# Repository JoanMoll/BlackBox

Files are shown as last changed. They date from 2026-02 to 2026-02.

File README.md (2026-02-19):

# BlackBox — Room Health / Environmental Monitoring PCB

Custom KiCad PCB for a battery-powered, ESP32-class device intended to monitor room/environment conditions and log data locally.

## Design previews

### 3D view
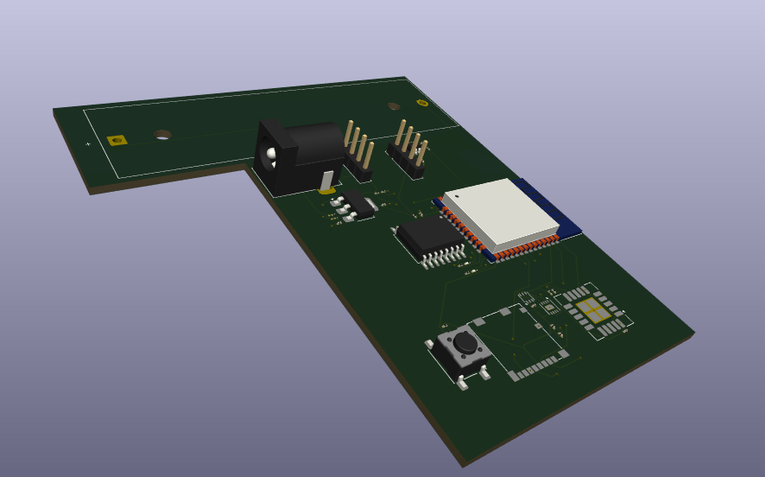
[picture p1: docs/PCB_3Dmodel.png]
PCB 3D Render


### PCB layout
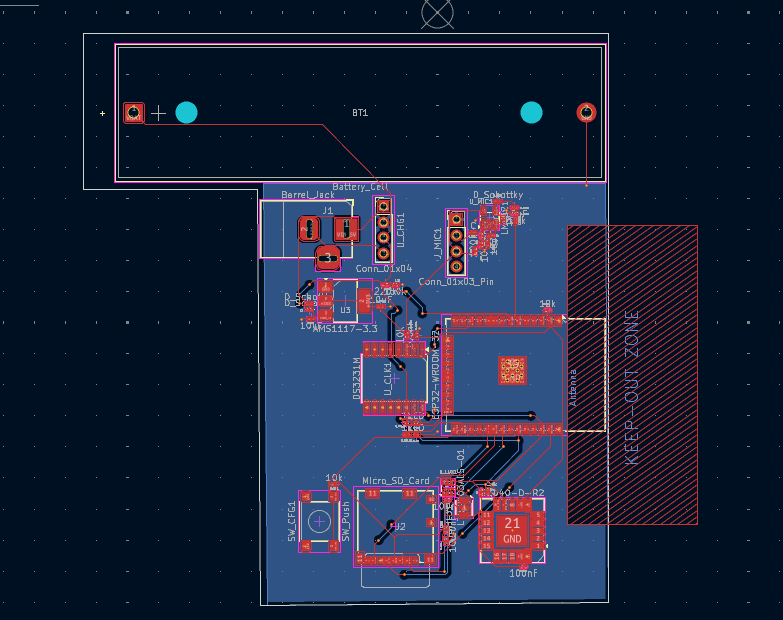
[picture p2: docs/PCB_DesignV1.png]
PCB Layout


### Schematic
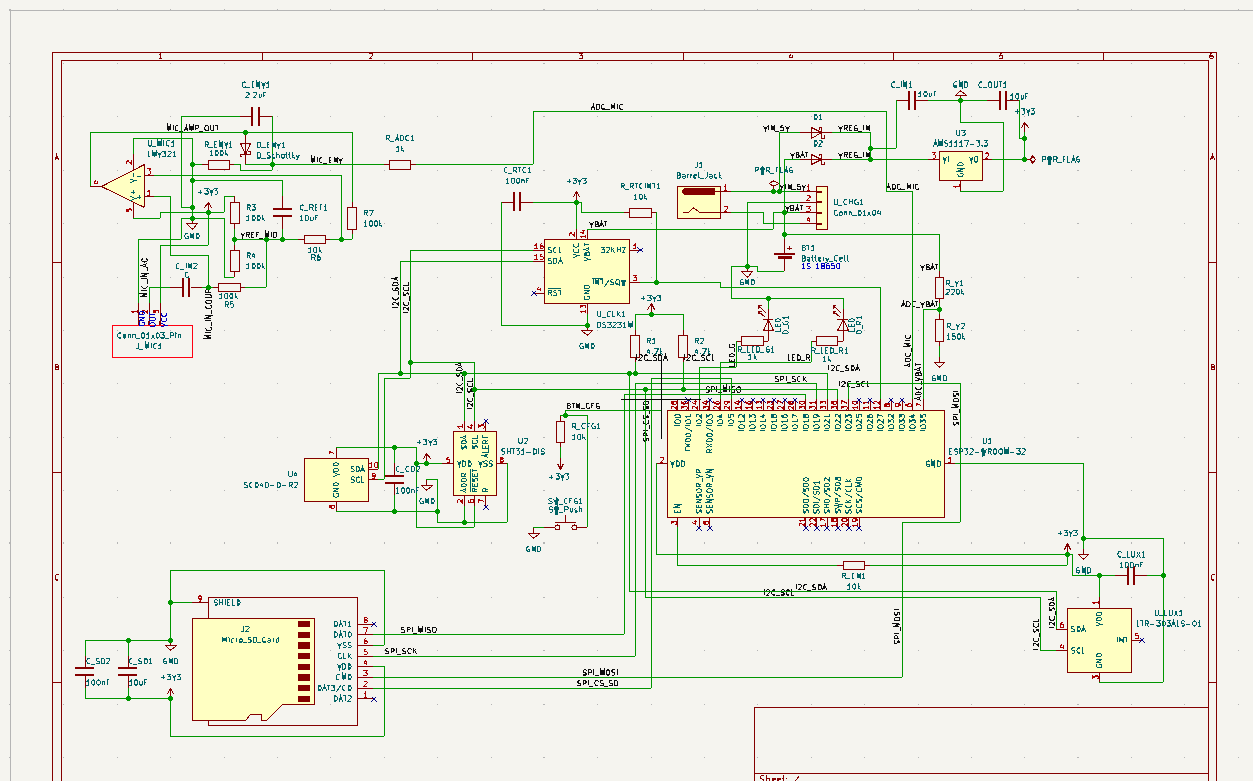
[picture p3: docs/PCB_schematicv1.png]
Schematic


## Project overview
BlackBox is a hardware design project focused on a practical embedded system that combines sensing, local storage, battery operation, and an ESP32-class MCU. The goal is a compact “room health” monitoring unit that can collect measurements and store them for later analysis.

## Intended system (high-level)
- MCU / Wireless: ESP32-class microcontroller (e.g., ESP32-S3)
- Sensors: LDR (ambient light), ultrasonic (distance/proximity), plus analog sensor input(s)
- Analog front-end: LMV321 op-amp stage for signal conditioning/amplification
- Storage: micro-SD card for local data logging
- Power: battery input (VBAT) with 3.3 V regulation and battery management/protection

## Repository contents
- KiCad project: `.kicad_pro`
- Schematic: `.kicad_sch`
- PCB layout: `.kicad_pcb`
- 3D model export: `.step` (if included)
- Documentation images: `docs/pcb_3d.png`, `docs/pcb_layout.png`, `docs/schematic.png`

## How to open and review
1. Install KiCad (v7+ recommended).
2. Open the `.kicad_pro` file.
3. Review the schematic (`.kicad_sch`) and PCB layout (`.kicad_pcb`).
4. Run ERC (schematic checks) and DRC (PCB checks) inside KiCad.

## Status
- Schematic and PCB layout created
- Next: final DRC/ERC pass and documentation polish
- Next: order PCB and bring-up tests (power rails, SD, sensor IO)
- Next: firmware (sampling + logging format) and enclosure design

## Skills demonstrated
- End-to-end PCB design workflow in KiCad (schematic capture, layout, manufacturable design)
- Embedded hardware system design (power, sensing, analog conditioning, storage interfaces)
- Clear engineering documentation for review (renders + structured project summary)

## License
If no license file is included, all rights reserved (portfolio viewing only).

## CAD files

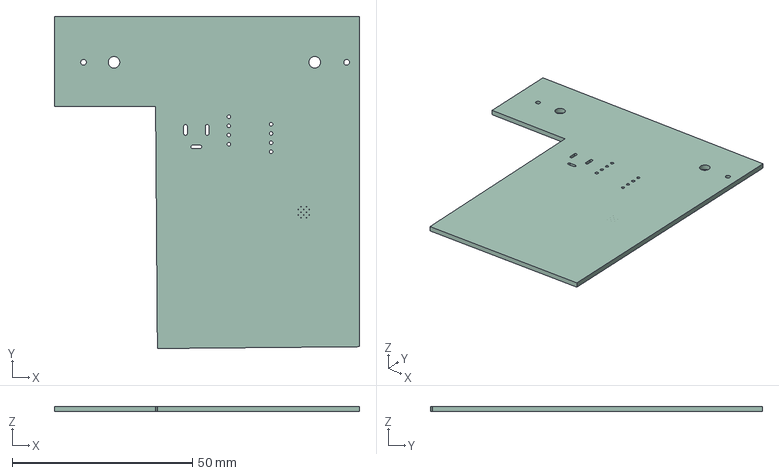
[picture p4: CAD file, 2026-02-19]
RoomHealthBlackBox.step
84.5 x 92.0 x 1.51 mm

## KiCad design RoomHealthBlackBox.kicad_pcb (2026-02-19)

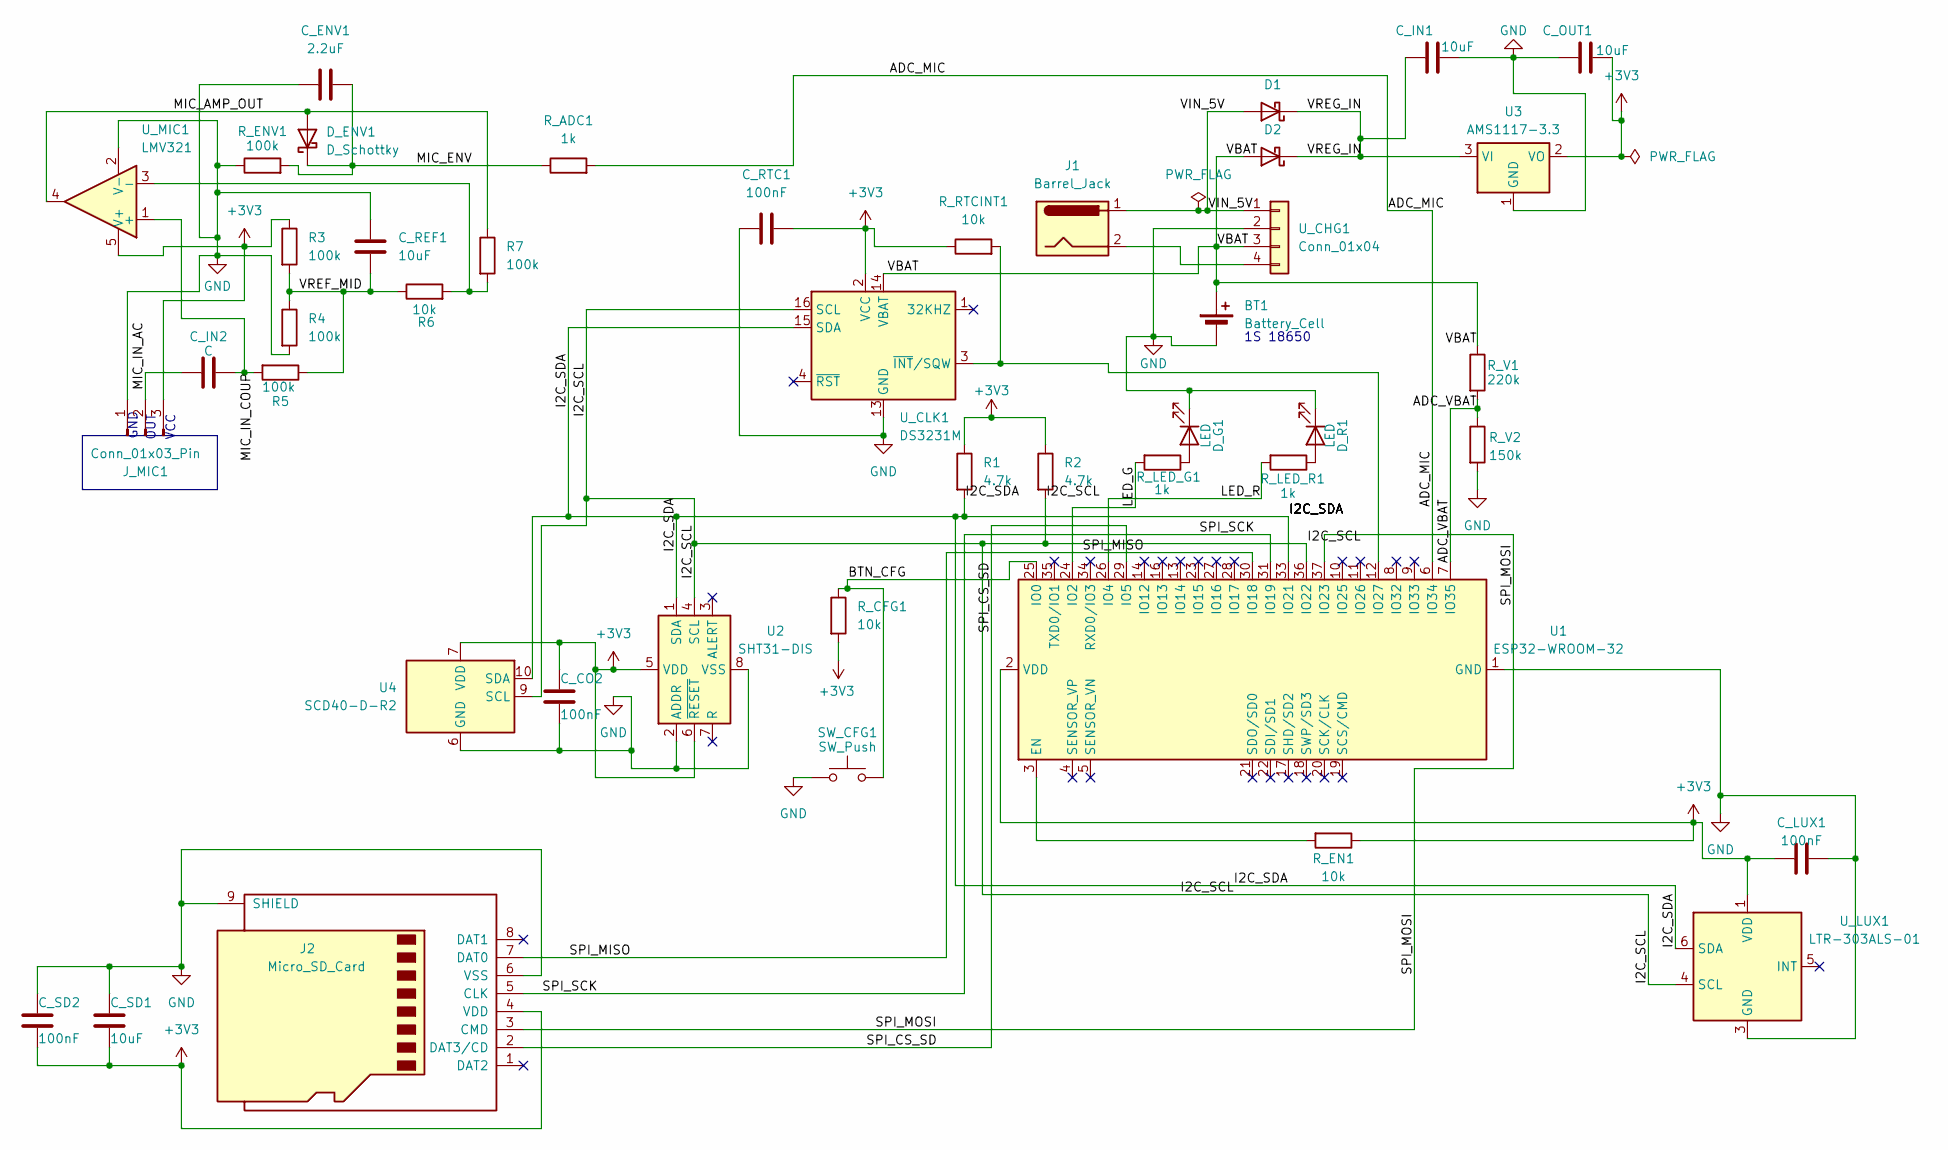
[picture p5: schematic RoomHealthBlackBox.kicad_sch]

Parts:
BT1: Battery_Cell; BatteryHolder_MPD_BH-18650-PC
C_CO2: 100nF; C_0201_0603Metric
C_ENV1: 2.2uF; C_0201_0603Metric
C_IN1: 10uF; C_0201_0603Metric
C_IN2: C; C_0201_0603Metric
C_LUX1: 100nF; C_0201_0603Metric
C_OUT1: 10uF; C_0201_0603Metric
C_REF1: 10uF; C_0201_0603Metric
C_RTC1: 100nF; C_0201_0603Metric
C_SD1: 10uF; C_0201_0603Metric
C_SD2: 100nF; C_0201_0603Metric
D1, D2: D_Schottky; D_0201_0603Metric
D_ENV1: D_Schottky; D_0201_0603Metric
D_G1: LED; LED_0201_0603Metric
D_R1: LED; LED_0201_0603Metric
J1: Barrel_Jack; BarrelJack_Horizontal
J2: Micro_SD_Card; microSD_HC_Molex_104031-0811
J_MIC1: Conn_01x03_Pin; PinHeader_1x04_P2.54mm_Vertical
R1, R2: 4.7k; R_0201_0603Metric
R3, R4, R5, R7: 100k; R_0201_0603Metric
R6: 10k; R_0201_0603Metric
R_ADC1: 1k; R_0201_0603Metric
R_CFG1: 10k; R_0201_0603Metric
R_EN1: 10k; R_0201_0603Metric
R_ENV1: 100k; R_0201_0603Metric
R_LED_G1: 1k; R_0201_0603Metric
R_LED_R1: 1k; R_0201_0603Metric
R_RTCINT1: 10k; R_0201_0603Metric
R_V1: 220k; R_0201_0603Metric
R_V2: 150k; R_0201_0603Metric
SW_CFG1: SW_Push; SW_SPST_PTS645Sx43SMTR92
U1: ESP32-WROOM-32
U2: SHT31-DIS; Sensirion_DFN-8-1EP_2.5x2.5mm_P0.5mm_EP1.1x1.7mm
U3: AMS1117-3.3; SOT-223-3_TabPin2
U4: SCD40-D-R2; Sensirion_SCD4x-1EP_10.1x10.1mm_P1.25mm_EP4.8x4.8mm
U_CHG1: Conn_01x04; PinHeader_1x04_P2.54mm_Vertical
U_CLK1: DS3231M; SOIC-16W_7.5x10.3mm_P1.27mm
U_LUX1: LTR-303ALS-01; Lite-On_LTR-303ALS-01
U_MIC1: LMV321; SOT-23-5

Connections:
+3V3: C_CO2.1, C_LUX1.1, C_OUT1.2, C_RTC1.2, C_SD1.2, C_SD2.2, J2.4 (VDD), J_MIC1.3, R1.1, R2.1, R3.1, R_CFG1.2, R_EN1.1, R_RTCINT1.1, U1.2 (VDD), U2.5 (VDD), U2.6 (~RESET), U3.2 (VO), U4.7 (VDD), U4.19 (VDD), U_CLK1.2 (VCC), U_LUX1.1 (VDD), U_MIC1.5 (V+)
/ADC_MIC: R_ADC1.2, U1.6 (IO34)
/ADC_VBAT: R_V1.2, R_V2.1, U1.7 (IO35)
/BTN_CFG: R_CFG1.1, SW_CFG1.2, U1.25 (IO0)
/I2C_SCL: R2.2, U1.36 (IO22), U2.4 (SCL), U4.9 (SCL), U_CLK1.16 (SCL), U_LUX1.4 (SCL)
/I2C_SDA: R1.2, U1.33 (IO21), U2.1 (SDA), U4.10 (SDA), U_CLK1.15 (SDA), U_LUX1.6 (SDA)
/LED_G: R_LED_G1.2, U1.24 (IO2)
/LED_R: R_LED_R1.2, U1.26 (IO4)
/MIC_AMP_OUT: D_ENV1.2 (A), R7.1, U_MIC1.4
/MIC_ENV: C_ENV1.2, D_ENV1.1 (K), R_ADC1.1, R_ENV1.2
/MIC_IN_AC: C_IN2.2, J_MIC1.2
/MIC_IN_COUP: C_IN2.1, R5.2, U_MIC1.1 (+)
/SPI_CS_SD: J2.2 (DAT3/CD), U1.29 (IO5)
/SPI_MISO: J2.7 (DAT0), U1.30 (IO18)
/SPI_MOSI: J2.3 (CMD), U1.37 (IO23)
/SPI_SCK: J2.5 (CLK), U1.31 (IO19)
/VBAT: BT1.1 (+), D2.2 (A), R_V1.1, U_CHG1.3, U_CLK1.14 (VBAT)
/VIN_5V: D1.2 (A), J1.1, U_CHG1.1
/VREF_MID: C_REF1.2, R3.2, R4.1, R5.1, R6.1
/VREG_IN: C_IN1.2, D1.1 (K), D2.1 (K), U3.3 (VI)
GND: BT1.2 (-), C_CO2.2, C_ENV1.1, C_IN1.1, C_LUX1.2, C_OUT1.1, C_REF1.1, C_RTC1.1, C_SD1.1, C_SD2.1, D_G1.1 (K), D_R1.1 (K), J2.6 (VSS), J2.9 (SHIELD), J_MIC1.1, R4.2, R_ENV1.1, R_V2.2, SW_CFG1.1, U1.1 (GND), U1.15 (GND), U1.38 (GND), U1.39 (GND), U2.2 (ADDR), U2.8 (VSS), U2.9 (VSS), U3.1 (GND), U4.6 (GND), U4.20 (GND), U4.21 (GND), U_CHG1.2, U_CLK1.5 (GND), U_CLK1.6 (GND), U_CLK1.7 (GND), U_CLK1.8 (GND), U_CLK1.9 (GND), U_CLK1.10 (GND), U_CLK1.11 (GND), U_CLK1.12 (GND), U_CLK1.13 (GND), U_LUX1.3 (GND), U_MIC1.2 (V-)
unnamed: D_G1.2 (A), R_LED_G1.1
unnamed: D_R1.2 (A), R_LED_R1.1
unnamed: R_EN1.2, U1.3 (EN)
unnamed: R_RTCINT1.2, U1.12 (IO27), U_CLK1.3 (~INT/SQW)
unnamed: J1.2, U_CHG1.4
unnamed: R6.2, R7.2, U_MIC1.3 (-)

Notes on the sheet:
OUT
GND
1S 18650
VCC

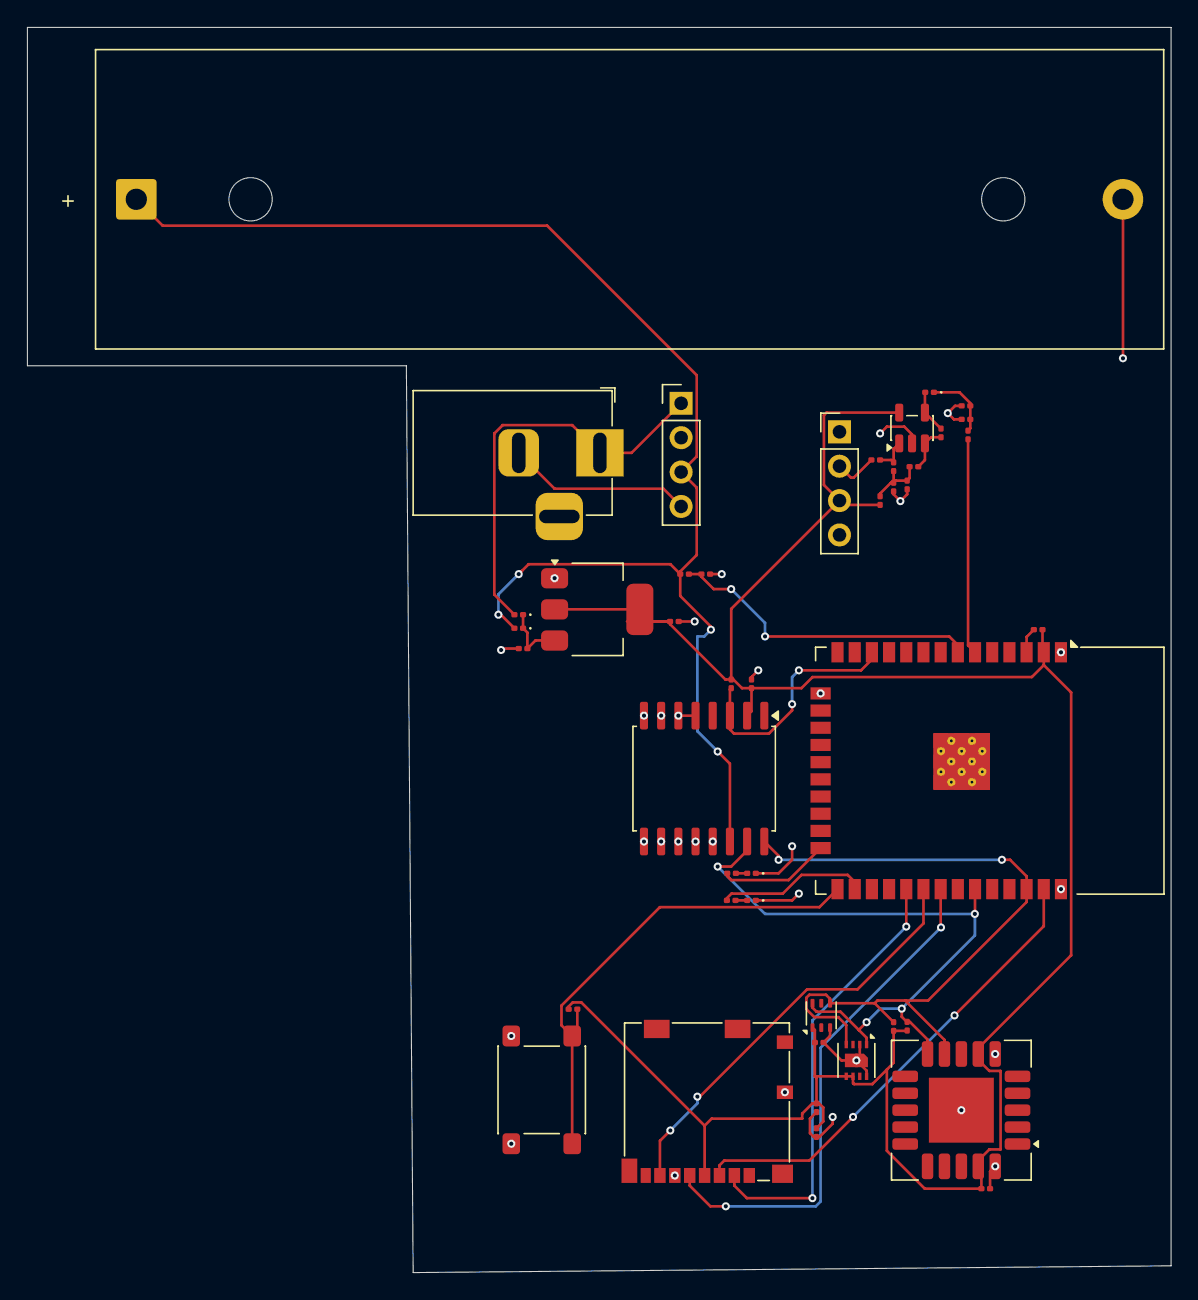
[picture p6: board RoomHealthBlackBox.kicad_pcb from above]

Board: 2 copper layers, 84.5 x 92.0 mm, 44 parts (0 on the bottom side), 27 nets.

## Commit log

2026-02-19 Create README for BlackBox environmental monitoring device
    Added README.md with project overview and details.
2026-02-19 Clean repo structure: docs and fab, remove backups
    [RoomHealthBlackBox-B_Cu.gbl, RoomHealthBlackBox-B_Mask.gbs, RoomHealthBlackBox-B_Paste.gbp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]
2026-02-19 Update PCB images in README
    Updated image references in the README to new files.
